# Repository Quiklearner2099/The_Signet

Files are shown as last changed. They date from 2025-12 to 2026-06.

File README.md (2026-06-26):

<div align="center">







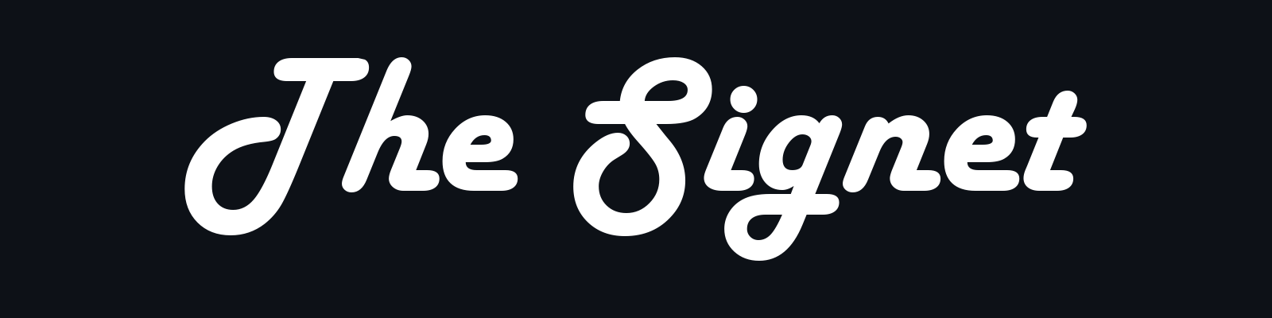
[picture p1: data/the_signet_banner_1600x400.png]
The Signet banner



[]()
[]()
Visitors

<h1>BIG BROTHER IS WATCHING YOU…<br/>Send him a message.</h1>

<strong>A Morse Code Beacon for Protest Messaging / Video Steganography</strong>

<p>
  <strong>The Signet</strong> is a small, WiFi configurable beacon designed to embed a message
  (<strong>encoded in Morse code</strong>)<br>into <strong>recorded video footage</strong>
  using a blinking light source.
</p>

<!-- ADD HERE -->
<a href="https://www.tindie.com/products/signet-systems/the-signet/">
  
</a>

</div>

<div align="center">

---

### **NEW TO THE SIGNET?**

<a href="https://quiklearner2099.github.io/The_Signet/Tutorial/tutorial_demo.html">
  
</a>

**Learn how to use The Signet in minutes with our step-by-step interactive guide!**

---

</div>

## Feature Breakdown

<div align="center">

| 🔩 Hardware | 💾 Firmware |
|:---|:---|
| **XIAO ESP32-C6 SoC** — cheap, small, capable | **Plain text → International Morse code** signaling |
| **Dual emitters** — RGB LED + 950nm IR LED | **Language agnostic** — enc/decodes the same worldwide |
| **500 mAh Li-Po** with dis/charge protection | **Visible / Discreet modes** — selectable RGB / IR output |
| **USB-C charging** — can be used while charging | **WiFi AP+CP** — browser-based UI; no app required |
| **Magnetic mounting** — for fast, easy placement | **No internet connectivity** — operates fully offline |
| **Easy assembly and quick builds** | **Auto WiFi shutdown** after 60 seconds of UI inactivity |
| **Snap-fit 3D-printable enclosure** (2 pieces) | **OTA firmware updates** — upload new firmware via the captive portal |
| **Minimal soldering required** | **True stateless design** — zero bytes persisted to flash |

 **NO telemetry, NO accounts, NO bullshyte**

Click [HERE](https://github.com/Quiklearner2099/The_Signet/blob/main/Documentation/The_Signet_Security_Brief_v1.3.0.pdf) to view the Security Brief  
</div>

<hr/>

<h2>Output Modes</h2>

<ul>
  <li>
    <strong>Visible</strong> — uses an <strong>RGB LED</strong> for human-eye detection
    <em>(obvious in person, obvious on camera)</em>
  </li>
  <li>
    <strong>Discreet</strong> — uses an <strong>IR LED</strong> for low-visibility messaging
    <em>(typically not noticeable to most bystanders, but may still be captured on video depending on the camera)</em>
  </li>
</ul>

<hr/>

<h2>Build Guide</h2>

<p>
  Watch the complete 14-minute build tutorial to assemble your own Signet device:
</p>

<div align="center">
  <a href="https://odysee.com/@the_signet:7/Signet_Build_Guide:8?r=DPS7K88vV2efrcF32mZreA2FPBWHjBPD">
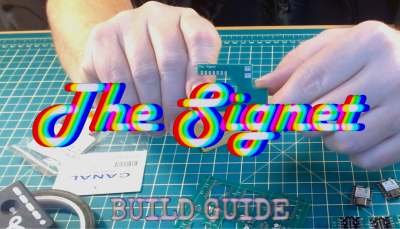
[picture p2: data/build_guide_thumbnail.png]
The Signet Build Tutorial
    
  </a>
  <br>
  <strong>▶️ Click to watch on Odysee</strong>
</div>

<hr/>

<h2>:question:Why this exists</h2>

<h3>:loudspeaker:Durable speech when platforms fail</h3>

<p>
  In many places, digital censorship and content suppression are rising.
  <strong>The Signet</strong> is built for situations where people need to communicate ideas in public—
  especially during peaceful demonstrations—without relying on platforms, audio, or live speech.
</p>

<p>
  Instead of shouting a message (which can provoke instant confrontation or get drowned out),
  <strong>The Signet</strong> lets a message persist inside the footage itself—so it can be discovered later
  in recordings from participants, journalists, or fixed cameras.
  The point is durability: the message travels with the video.
</p>

<blockquote>
  <strong>
    <strong>The Signet</strong> uses standard International Morse Code (ITU), ensuring global readability
    and compatibility with both human and machine decoding. A message embedded in footage can’t be muted, 
    algorithmically downranked, or “lost in the crowd” the same way a post can.
  </strong>
</blockquote>

<h3>:video_camera:Footage continuity &amp; tamper indication</h3>

<p>
  <strong>The Signet</strong> can also be used as a continuity marker for recorded footage.
  By embedding a continuous, time-ordered Morse message into the recording,
  the signal should remain consistent from start to finish.
</p>

<ul>
  <li>
    Unexpected gaps, jumps, or resets may indicate
    cuts, dropped frames, edits, or tampering.
  </li>
  <li>
    This can help viewers and investigators spot continuity breaks
    that might otherwise go unnoticed.
  </li>
</ul>

<hr/>

<h2>:thinking:How this differs from watermarking</h2>

<p>
  While <strong>The Signet</strong> and watermarking both involve embedding information into video,
  they solve very different problems and operate in fundamentally different ways.
</p>

<h3>Watermarking</h3>

<ul>
  <li>Added <strong>after recording</strong> during editing or encoding</li>
  <li>Relies on digital pixel or compression manipulation</li>
  <li>Usually invisible and algorithmic</li>
  <li>Can often be removed or degraded through re-encoding</li>
  <li>Primarily serves ownership and copyright enforcement</li>
</ul>

<h3>The Signet</h3>

<ul>
  <li>Embeds information <strong>at the moment of recording</strong></li>
  <li>Uses optical signaling (visible or IR light)</li>
  <li>Independent of codecs, platforms, and formats</li>
  <li>Becomes part of the physical scene, not a digital layer</li>
  <li>Can reveal edits through continuity breaks</li>
</ul>

<blockquote>
  <strong>Watermarking alters the media.<br/>
  The Signet alters the scene.</strong>
</blockquote>

<hr/>

<h2>:closed_lock_with_key:Privacy &amp; Security by Design</h2>

<ul>
  <li><strong>No app required</strong> — browser-based configuration only</li>
  <li><strong>No internet connectivity</strong> — never connects to cloud services</li>
  <li><strong>Temporary local Wi-Fi AP</strong> for configuration only</li>
  <li><strong>Automatic AP shutdown</strong> after 60 seconds of inactivity</li>
  <li><strong>MAC address locking</strong> — first device to connect gets exclusive access; AP shuts down when that device disconnects</li>
  <li><strong>No persistent logs or telemetry</strong></li>
  <li><strong>True stateless design</strong> — zero bytes written to flash; all settings (including language) reset on power cycle</li>
  <li><strong>OTA updates are local-only</strong> — firmware uploaded directly through the on-device Wi-Fi AP; no cloud, no remote access</li>
  <li><strong>Anti-forensics</strong> — nothing to recover from the device; no message history, no usage patterns</li>
</ul>

<hr/>

## :desktop_computer:Development Setup

### Quick Start with GitHub Codespaces ⭐ RECOMMENDED

The easiest way to contribute is to use GitHub Codespaces - a cloud-based development environment with everything pre-configured:

1. Click the green **"Code"** button on the repository
2. Select the **"Codespaces"** tab
3. Click **"Create codespace on main"**
4. Wait for **"The Signet - ESP32 C6 Arduino"** environment to build (~2-3 minutes)
5. Once ready, you'll have a full VS Code environment with:
   - Arduino CLI pre-installed
   - ESP32 C6 board package configured
   - All required libraries (FastLED, ArduinoJson, etc.)
   - C++ IntelliSense properly configured
   - Ready to compile and verify code

**No local setup required!** All dependencies are handled automatically.

### Local Development (Alternative)

If you prefer to work locally:

1. Install [Arduino IDE 2.x](https://www.arduino.cc/en/software) or [PlatformIO](https://platformio.org/)
2. Install the ESP32 board package (version 3.0.0 or later)
3. Install required libraries via the Library Manager:
   - **FastLED** (v3.5.x)
   - **ArduinoJson** (v6.x)
4. Select board: **ESP32C6 Dev Module**
5. Open `The_Signet.ino` and compile

<h2>Ethical Use</h2>

<p>
  The Signet is intended to support lawful, non-violent freedom of expression,
  documentation, and artistic or journalistic messaging.
  It must not be used to enable harm, harassment, intimidation, illegal activity,
  or to mislead people about what is being recorded or communicated.
</p>

## Support This Project

<a href="https://www.buymeacoffee.com/Quiklearner2099" target="_blank">
  Buy Me A Coffee
</a>

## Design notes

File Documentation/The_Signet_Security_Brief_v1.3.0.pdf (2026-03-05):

# The Signet

# Security Brief — Firmware v1.3.0+

Version 1.3.0 firmware represents the most security-hardened release to date, incorporating lessons from two independent audits and real-world field testing. Every design decision prioritizes the operator's safety, anonymity, and plausible deniability.

Zero Persistence Architecture

The Signet writes zero bytes to permanent storage during normal operation. Messages exist only in volatile RAM and are irrecoverably destroyed the instant the device loses power. There is no message history, no activity log, no usage record, and no settings file written to flash —ever.
Previous firmware versions stored a two-byte language preference in non-volatile storage. Version 1.3.0 eliminates even this, achieving a fully stateless design. The language selection modal appears fresh on every boot, and the chosen language lives only in RAM for the duration of that session. If the device is seized, powered off, or its battery dies, there is nothing to recover. Flash forensics will find only the firmware binary itself and static UI assets (fonts, images). No user-generated data touches persistent memory under any circumstances.

No Telemetry. No Logs. No Exceptions.

The Signet firmware contains zero outbound network code. There is no HTTP client library, no WiFi client mode, no DNS lookup to external servers, no cloud dependency, no analytics SDK, no crash reporter, and no phone-home mechanism of any kind. This has been verified through static analysis of every `#include` directive and every function call in the codebase.
The device operates exclusively as a WiFi Access Point. It creates a local network that allows a single connection; it never joins one. It serves a web UI to the connected client; it never contacts anything beyond that single direct connection. There are no beacon frames sent to probe for known networks, no mDNS broadcasts, and no service discovery announcements. The only RF emission is the AP's SSID beacon, and even that is time-limited (see below).

MAC Address Locking — Single Operator Exclusivity

When the first device connects to The Signet's WiFi access point and issues any API command, the firmware locks to that device's MAC address. From that point forward, no other device can control The Signet — even if it somehow connects to the WiFi network. The lock persists until the device is power -cycled.
This is enforced at the firmware level through `esp_wifi_ap_get_sta_list()`, comparing the requesting client's MAC against the locked MAC on every API call. Combined with the ESP32's `max_conn=1` parameter (which limits the AP to a single simultaneous WiFi client), this creates a two-layer access control: only one device can connect, and only the first device to authenticate gets command authority.

Automatic AP Shutdown on Disconnect

Version 1.3.0 introduces a critical improvement: when the locked operator disconnects from WiFi, the access point shuts down entirely. The firmware polls the station list each loop iteration, and the moment the locked client's MAC disappears, it executes a full shutdown sequence — DNS server stopped, `WiFi.softAPdisconnect(true)` called, WiFi radio turned off. No second device can connect during any window between disconnect and shutdown because the check runs continuously with no grace period.
After shutdown, the locked MAC address is scrubbed from RAM with `memset(lockedMac, 0, sizeof(lockedMac))`. This is a deliberate anti-forensics measure: even a cold-boot attack or live memory dump after the operator walks away will not reveal which device was controlling The Signet. Morse playback continues uninterrupted — the beacon keeps transmitting its message even with WiFi completely disabled.

Additional technical information and source code can be found at: https://github.com/Quiklearner2099/The_Signet

OTA Combination Lock — Physical Verification for Firmware Updates Over-the-air firmware updates are protected by a hardware-verified combination lock system. Before any firmware binary can be uploaded, the operator must:
1. Request a code — The device generates a random 3-digit code (each digit 1–9) using the ESP32's hardware random number generator (`esp_random()`).
2. Read the code from the LED — The RGB LED blinks the code physically: red blinks for digit one, green blinks for digit two, blue blinks for digit three. For example, 3 red blinks, 7 green blinks, 2 blue blinks = code 372.
3. Enter the code in the web UI — The operator types the three digits into color-coded input fields.
4. Upload the firmware — Only after successful code verification does the upload endpoint accept the binary.
The code is generated fresh each time and invalidated after a single successful use. This means an attacker cannot replay a previously observed code, and they cannot upload firmware without physical line-of-sight to the device's LED. The combination lock transforms OTA security from a pure software problem into a physical presence requirement.
Additionally, the firmware validates uploaded binaries against the ESP32 magic byte (0xE9), rejecting anything that isn't a legitimate ESP32 firmware image. The device uses a dual-partition OTA layout, enabling automatic rollback to the previous working firmware if an update fails mid-write.

60-Second WiFi Exposure Window The Signet's WiFi access point automatically shuts down after 60 seconds of inactivity. This minimizes the window during which the device's SSID is visible to passive WiFi scanners. The operator connects, configures their message, and the AP disappears — all within a brief window. The Morse beacon continues transmitting indefinitely after WiFi shutdown, operating in complete radio silence on the WiFi band.
This is a deliberate privacy trade-off: the unique SSID (which includes a MAC-derived suffix for operator identification of their own device) is only broadcast during the brief configuration period, not during the potentially hours-long transmission phase.

Randomized WiFi Channel Selection Each time The Signet boots, it randomly selects one of the three non-overlapping 2.4 GHz channels (1, 6, or 11) using the ESP32's hardware RNG. This provides automatic interference avoidance in congested RF environments and adds a minor layer of unpredictability — an observer cannot assume the device will always appear on the same channel between power cycles.

Defense-in-Depth Input Validation Every API endpoint enforces strict input validation and payload size limits as a defense against malformed or malicious requests:
- Payload size caps: `/api/update` and `/api/play` reject any request body exceeding 512 bytes (HTTP 413). `/api/language` caps at 256 bytes. These limits prevent buffer-based attacks and flash wear from oversized payloads.
- RGB value constraining: All color values are clamped to 0–255 using `constrain()`, preventing out-of-range writes.
- WPM bounds enforcement: Speed values are validated to the 5–20 WPM range before use, with a division-by-zero guard in the timing calculation.
- Language index validation: Language codes are bounds-checked against the valid range before any array access.
- Firmware header validation: OTA uploads are checked for the ESP32 magic byte (0xE9) before the write begins.

No App Required — Captive Portal Web UI The Signet requires no app installation, no account creation, no download, and no third-party dependency. The operator connects to the WiFi AP, and the device's captive portal detection triggers the web UI automatically. Version 1.3.0+ includes explicit handlers for every major platform's captive portal probe mechanism — Android, iOS, Windows 10/11, macOS, and Firefox — ensuring the UI appears reliably across devices without requiring the operator to manually navigate to an IP address.
This matters for security because there is no app binary that could be discovered on a seized phone, no account that could be subpoenaed, and no download history that could be forensically recovered. The entire interaction happens through a standard web browser session that leaves minimal trace.

Multi-Language Support Without Fingerprinting The Signet supports eight languages — English, Spanish, French, Russian, Simplified Chinese, Traditional Chinese, Farsi, and Arabic — with full right -to-left layout support for Arabic and Farsi. In v1.3.0, the language preference is never written to flash, eliminating it as a potential demographic fingerprint. The selection modal appears on every boot, and the choice is stored only in volatile RAM for that session.
dependencies (ArduinoJson, FastLED). Anyone can audit the code, verify the privacy claims, compile their own build, or fork the project entirely.

# The Signet

BIG BROTHER IS WATCHING YOU…. Send him a message.

Hand Made with Pride in Canada

quiklearner2099@proton.me
https://www.tindie.com/products/signet-systems/the-signet/

Thread Safety & Watchdog Protection

The firmware uses FreeRTOS primitives to ensure safe concurrent operation between the web server (running on the main loop) and the Morse playback task (running on a dedicated core):

- Mutex-protected text access: The message string is guarded by a FreeRTOS semaphore. Both read and write operations acquire the mutex with a 100ms timeout, with a safe fallback to "SOS" if the lock cannot be obtained.
- Atomic playback state: The `playing` flag uses `std::atomic<bool>` for lock-free, thread-safe reads and writes across tasks.
- Fatal mutex failure: If either the text mutex or OTA mutex fails to initialize at boot, the firmware halts execution entirely rather than running in an unsafe state.
- Task Watchdog Timer: A 60-second hardware watchdog timer automatically resets the device if the main loop hangs, protecting against denial-ofservice conditions or firmware bugs that could leave the device unresponsive.

Open Source Transparency

The Signet's firmware is fully open source. The complete `.ino` source code, schematics, and bill of materials are available for inspection. There are no binary blobs, no obfuscated modules, and no proprietary libraries beyond the standard ESP32 SDK and well-audited open-source dependencies (ArduinoJson, FastLED). Anyone can audit the code, verify the privacy claims, compile their own build, or fork the project entirely.

The device also ships unlocked by default — the operator can upload their own firmware at any time. The combination lock protects against unauthorized uploads, not against the owner's right to modify their own hardware.

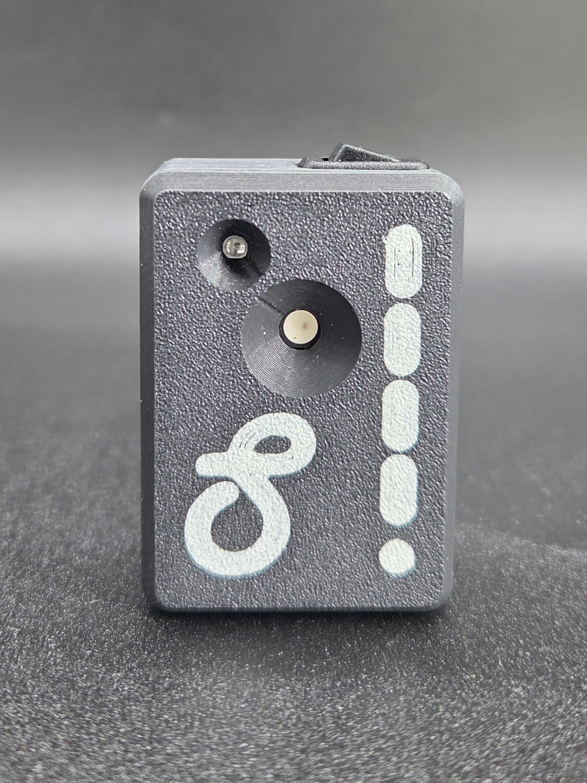
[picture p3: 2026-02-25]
Pictures/Signet 1.JPG

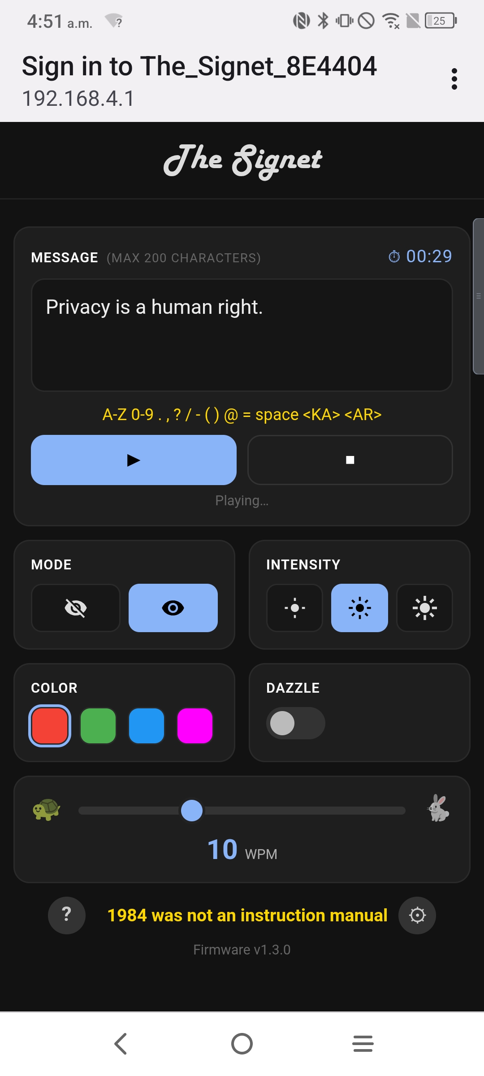
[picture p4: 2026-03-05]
Pictures/Main UI.jpg

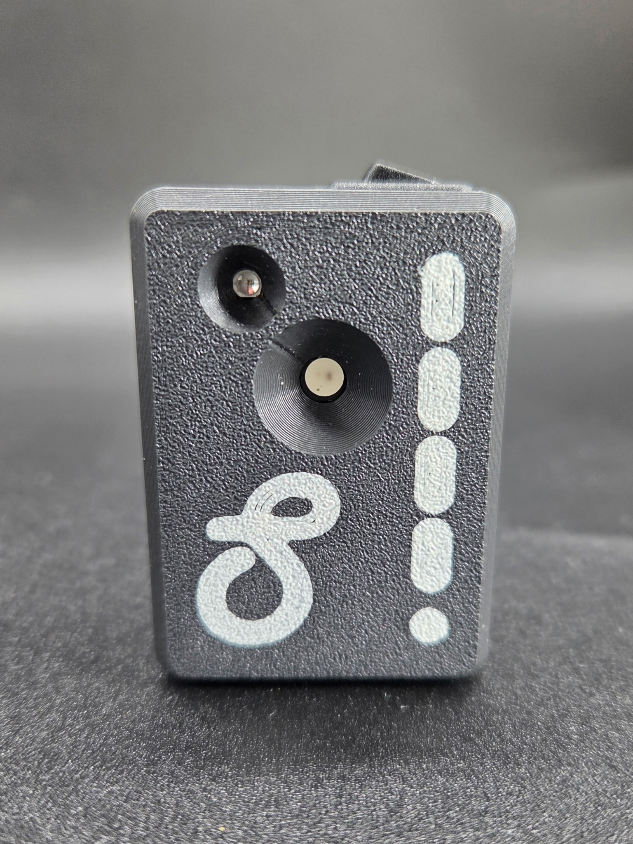
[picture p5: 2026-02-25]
Pictures/Signet 5.JPG

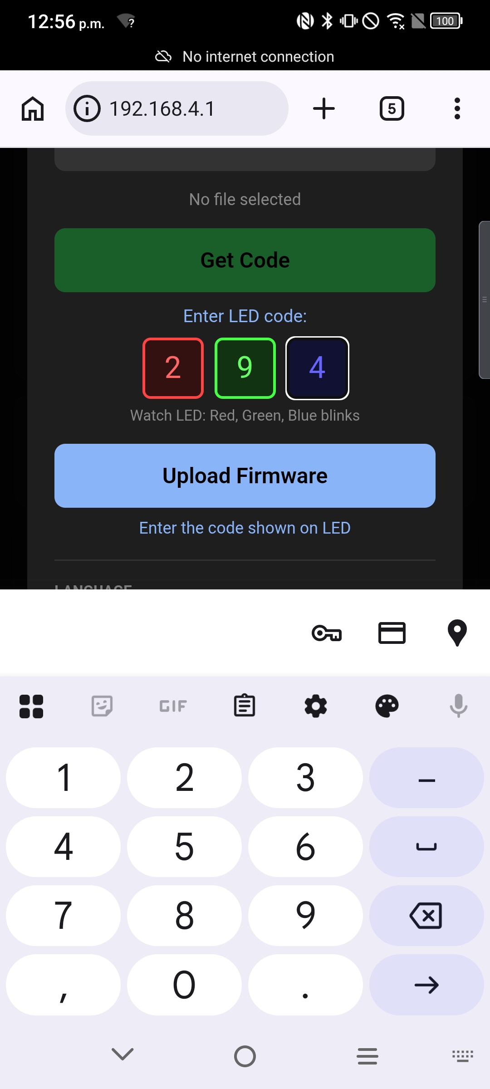
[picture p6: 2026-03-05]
Pictures/Firmware Combo-Lock.jpg

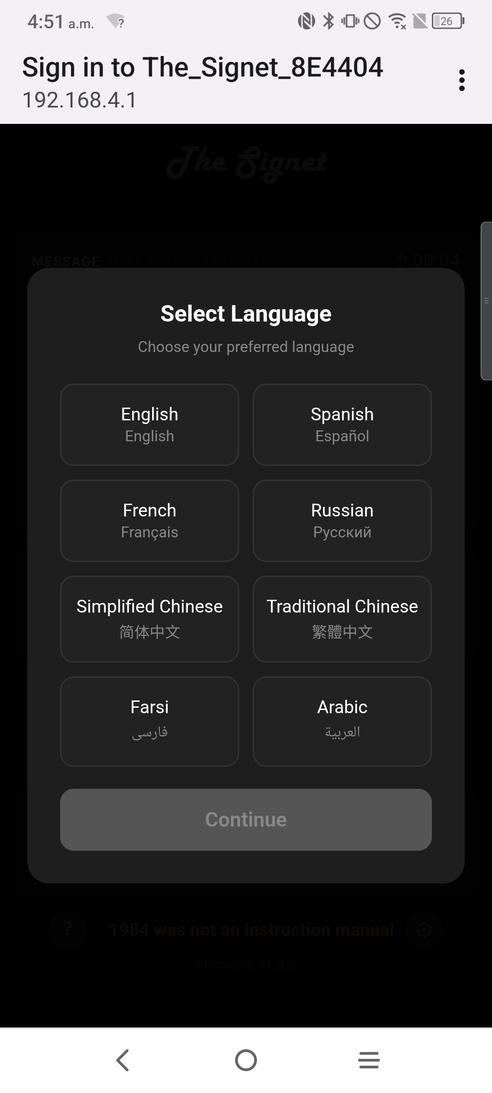
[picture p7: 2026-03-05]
Pictures/Language Selection.jpg

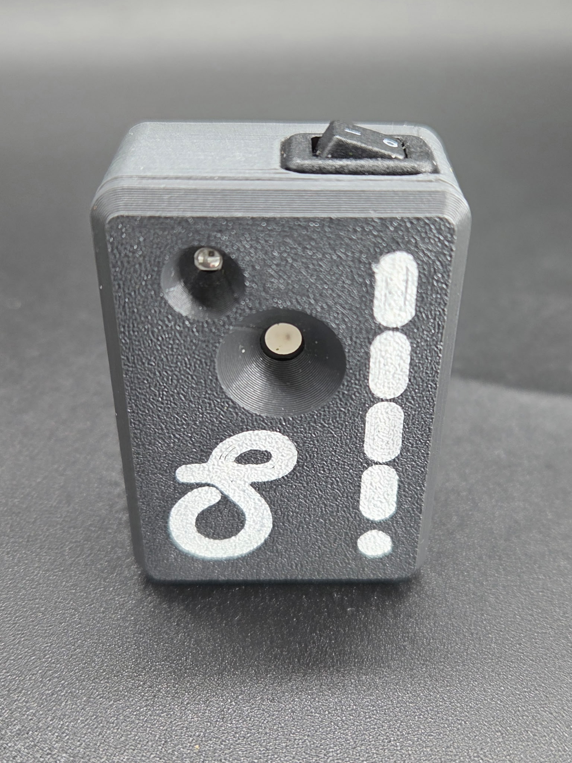
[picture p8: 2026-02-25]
Pictures/Signet 2.JPG

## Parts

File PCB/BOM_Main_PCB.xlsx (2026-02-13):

No. | Quantity | Comment | Designator | Footprint | Value | Manufacturer Part | Manufacturer | Supplier Part | Supplier | LCSC Stock | LCSC Price | JLCPCB Stock | JLCPCB Price
1 | 1 | NTD3528I8 | IR_LED | LED-SMD_L3.5-W2.8-FD-1 |  | NTD3528I8 | 国星光电 | C7464752 | LCSC |  |  | 59830 | 0.0088
2 | 1 | 2N3904 | Q1 | SOT-23-3_L2.9-W1.3-P1.90-LS2.4-BR |  | 2N3904 | GOODWORK(固得沃克) | C50176433 | LCSC |  |  | 6014 | 0.0009
3 | 1 | 47kΩ | R1 | R0805 | 47kΩ | 0805W8F4702T5E | UNI-ROYAL(厚声) | C17713 | LCSC |  |  | 2283443 | 0.0003
4 | 1 | 10Ω | R2 | R1206 | 10Ω | 1206W4F100JT5E | UNI-ROYAL(厚声) | C17903 | LCSC |  |  | 1513848 | 0.0005
5 | 1 | 270Ω | R3 | R0603 | 270Ω | 0603WAF2700T5E | UNI-ROYAL(厚声) | C22966 | LCSC |  |  | 573293 | 0.0002
6 | 1 | 100kΩ | R4 | R0603 | 100kΩ | 0603WAF1003T5E | UNI-ROYAL(厚声) | C25803 | LCSC |  |  | 8972216 | 0.0002
7 | 1 | WS2812B-B/T | RGB_LED | LED-SMD_4P-L5.0-W5.0-TL_WS2812B-B |  | WS2812B-B/T | worldsemi | C2761795 | LCSC |  |  | 167977 | 0.0114

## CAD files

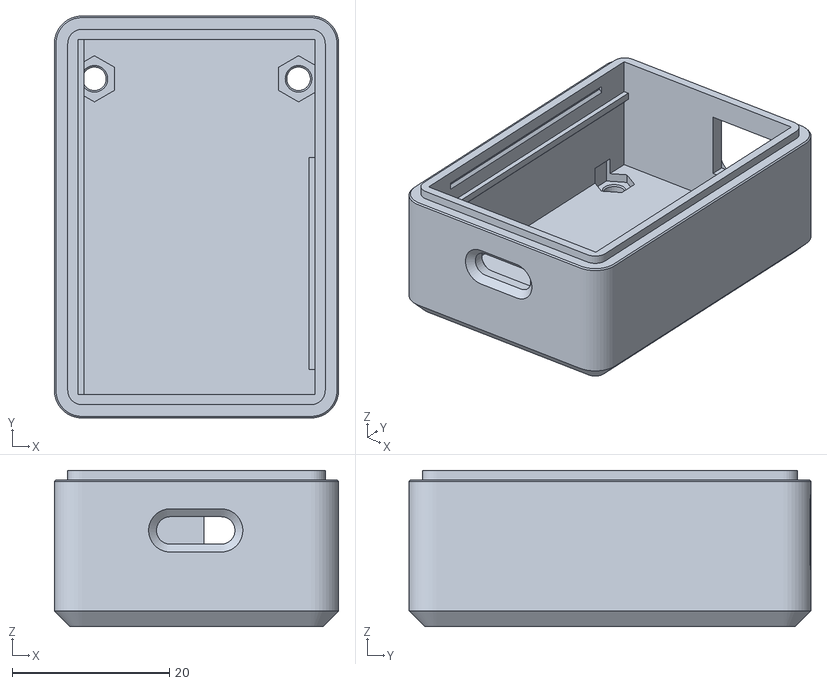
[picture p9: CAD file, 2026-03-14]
Housing/Signet_CASE_Beltclip_Edition.stl
36.2 x 51.2 x 19.9

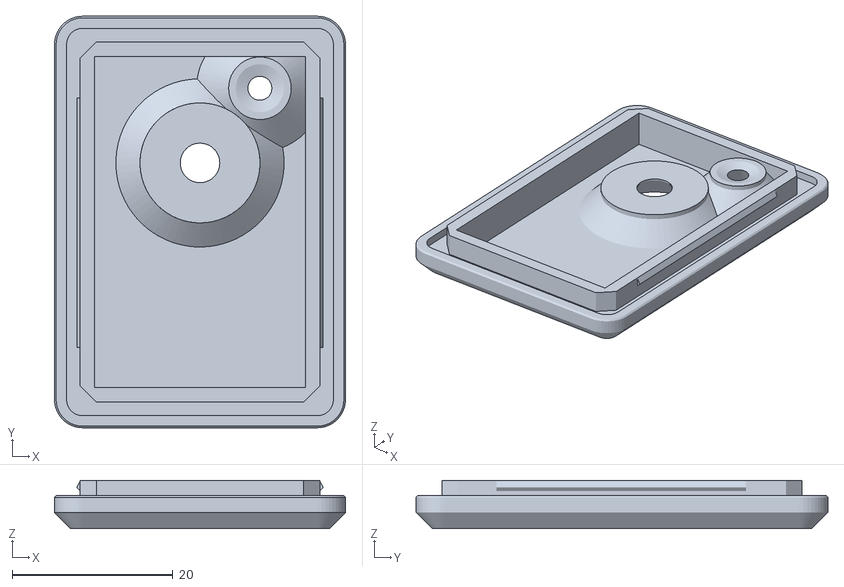
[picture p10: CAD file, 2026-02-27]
Housing/Lid.stl
36.2 x 51.2 x 6.00

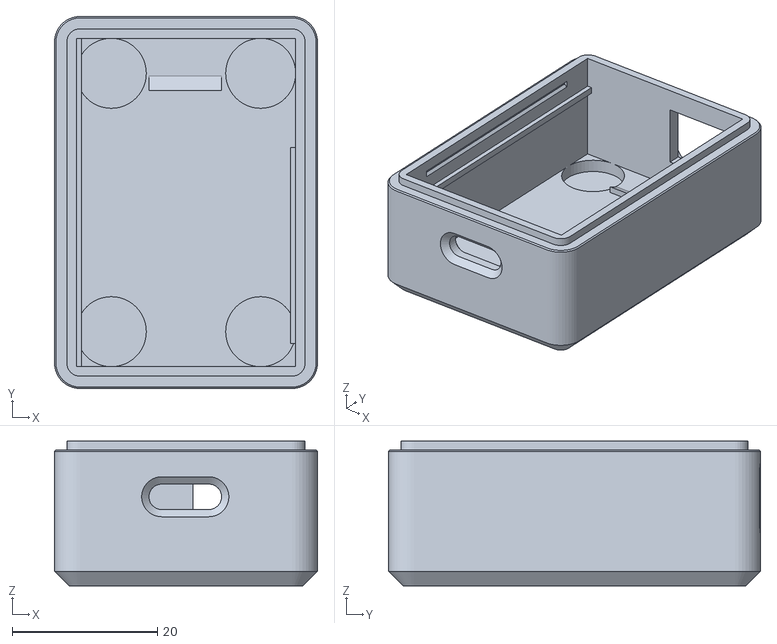
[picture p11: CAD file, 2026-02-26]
Housing/Signet_CASE_9.5x1.6mm_Magnets.stl
36.2 x 51.2 x 19.9

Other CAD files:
Housing/Signet_CASE_10x1.5mm_Magnets.stl

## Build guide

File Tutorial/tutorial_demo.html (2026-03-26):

# The Signet

This interactive tutorial is optimized for desktop viewing.

Please visit on a computer for the best experience.

View on GitHub (https://github.com/Quiklearner2099/The_Signet)

📱

## The Signet

Power on to begin

### Wi-Fi

Wi-Fi

Networks

HomeNetwork_5G📶

Neighbors_WiFi📶

The_Signet_A1B2C3📶

CoffeeShop_Guest📶

9:41

📶 🔋

💬

Messages

📧

Mail

🎵

Music

📷

Photos

❤️

Health

🗺️

Maps

📅

Calendar

⚙️

Settings

📞

🌐

📧

💬

## Select Language

Choose your preferred language

EnglishEnglish SpanishEspañol FrenchFrançais RussianРусский Chinese简体中文 Traditional繁體中文 Farsiفارسی Arabicالعربية

Continue

Big Brother

Click anywhere to send him a message...

← Back to Control

# Morse Code Reference

## Letters

Char | Code | Char | Code | Char | Code
A | ·− | J | ·−−− | S | ···
B | −··· | K | −·− | T | −
C | −·−· | L | ·−·· | U | ··−
D | −·· | M | −− | V | ···−
E | · | N | −· | W | ·−−
F | ··−· | O | −−− | X | −··−
G | −−· | P | ·−−· | Y | −·−−
H | ···· | Q | −−·− | Z | −−··
I | ·· | R | ·−·

## Numbers

Char | Code | Char | Code
0 | −−−−− | 5 | ·····
1 | ·−−−− | 6 | −····
2 | ··−−− | 7 | −−···
3 | ···−− | 8 | −−−··
4 | ····− | 9 | −−−−·

## Prosigns

Tag | Code | Meaning
<KA> | −·−·− | Starting signal
<AR> | ·−·−· | End of message

The Signet

### Message (MAX 200 Characters)00:03

SOS

A-Z 0-9 . , ? / - ( ) @ = space <KA> <AR>

▶ ■

Idle

### Mode

### Intensity

### Color

### Dazzle

RGB flash

🐢

🐇

10 WPM

?1984 was not an instruction manual⚙

Firmware v1.3.1

### Firmware Update

Current: v1.3.1

Choose .bin File

No file selected

Get Code

Enter LED code:

Watch LED: Red, Green, Blue, Yellow blinks

Upload Firmware Close

← Back GitHub Repository (https://github.com/Quiklearner2099/The_Signet) Next →

Step 1 of 15

The Signet

RGB LED (Visible)

IR LED (Discreet)

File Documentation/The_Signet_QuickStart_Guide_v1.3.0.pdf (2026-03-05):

# The Signet

# Quick Start Guide — Firmware v1.3.0

STEP 1: Connect a USB-C cable to charge the device. Power on your Signet using the switch.
STEP 2: On your phone, tablet or computer, open your WiFi Settings and connect to “The_Signet_XXXXXX” where XXXXXX is unique to your device. No password required.
STEP 3: Give the connection a few seconds and the Captive Portal should appear. If not, open any web browser and navigate to http://192.168.4.1
STEP 4: Select your User Interface language from the list of available options that appears. See Figure 1
Note that ITU Morse code implementation remains regardless of selected language.
Step 5: Configure your Signet. See Figure 2

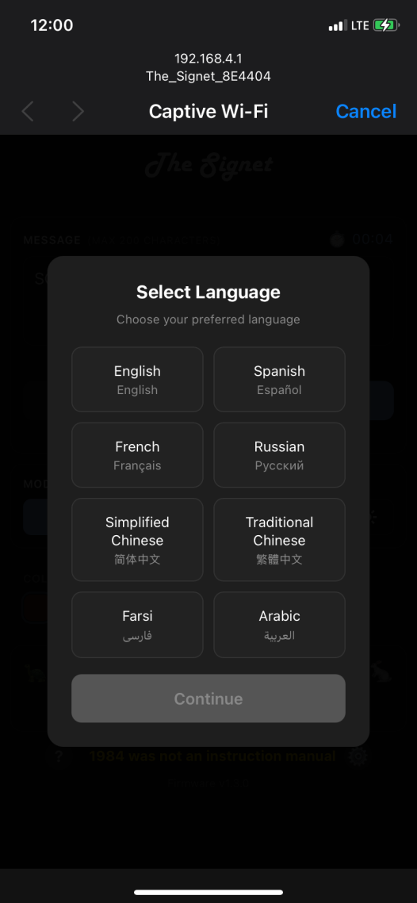
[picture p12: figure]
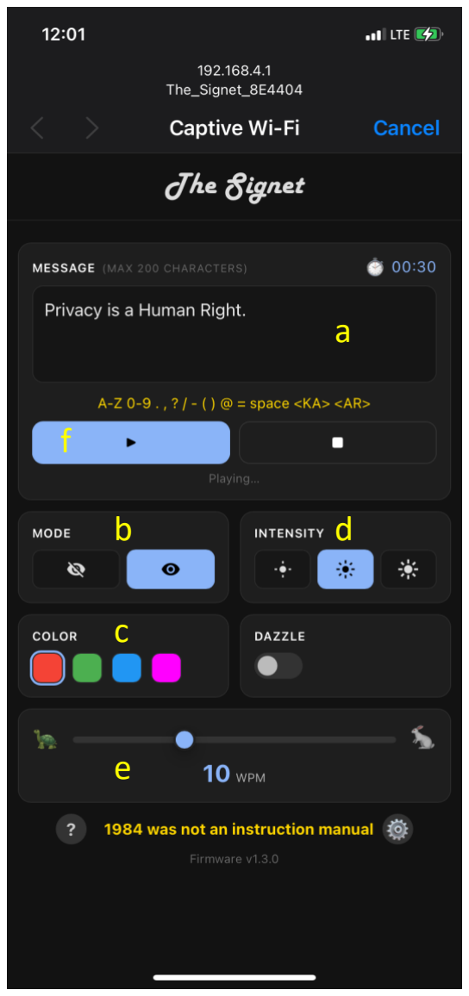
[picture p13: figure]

a. Type in your message (up to 200 Characters)
b. Select Mode: Invisible (IR)* or Visible (RGB)
c. Select Color: R*, G, B, or Custom (Visible Mode only)
d. Select Intensity (Low, Medium* or High)
e. Select your WPM speed (Words Per Minute) 5/10*/15/20
f. Press the Play button to begin message playback.
STEP 6: Close the Captive Portal or web browser and disconnect from the WiFi Access Point. Message playback will continue.
To reconnect, The Signet’s power must be cycled. Turn the switch OFF then ON again to relaunch the WiFi AP. This is normal operation and is meant to conserve battery life, protect your privacy and increase operational security.

*Default values

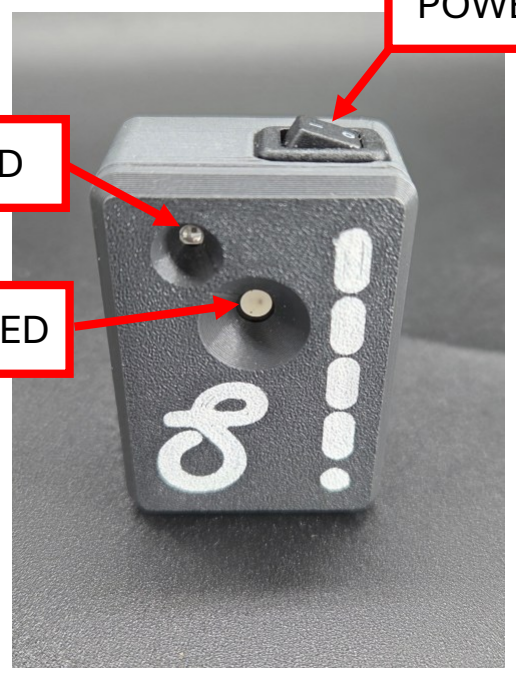
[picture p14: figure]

IR LED

RGB LED

POWER SWITCH

Additional technical information and source code can be found at: https://github.com/Quiklearner2099/The_Signet

iPhone UI examples

Figure 1 | Figure 2

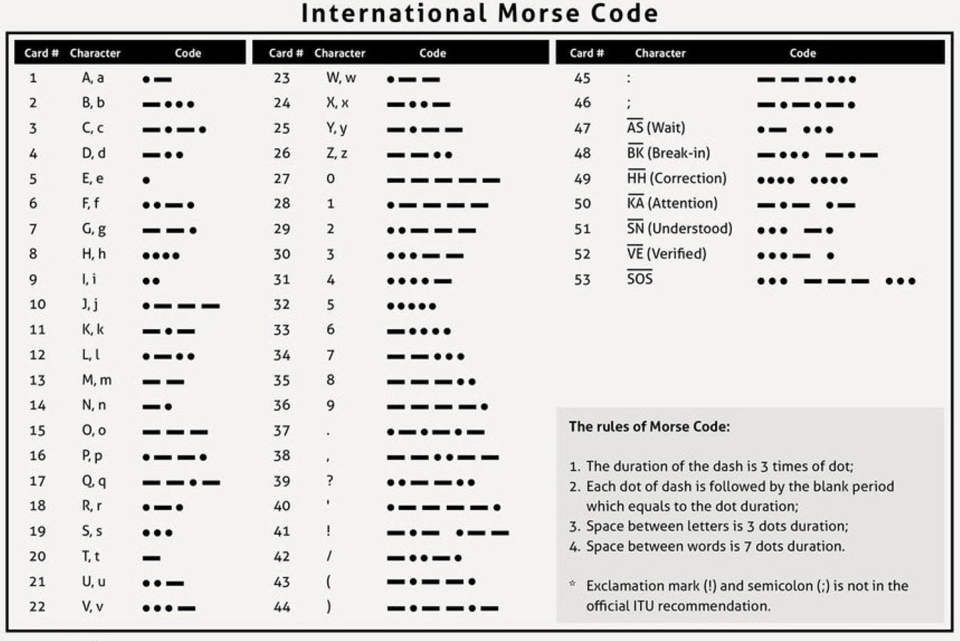
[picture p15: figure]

# The Signet

BIG BROTHER IS WATCHING YOU…. Send him a message.

Hand Made with Pride in Canada

quiklearner2099@proton.me
https://www.tindie.com/products/signet-systems/the-signet/

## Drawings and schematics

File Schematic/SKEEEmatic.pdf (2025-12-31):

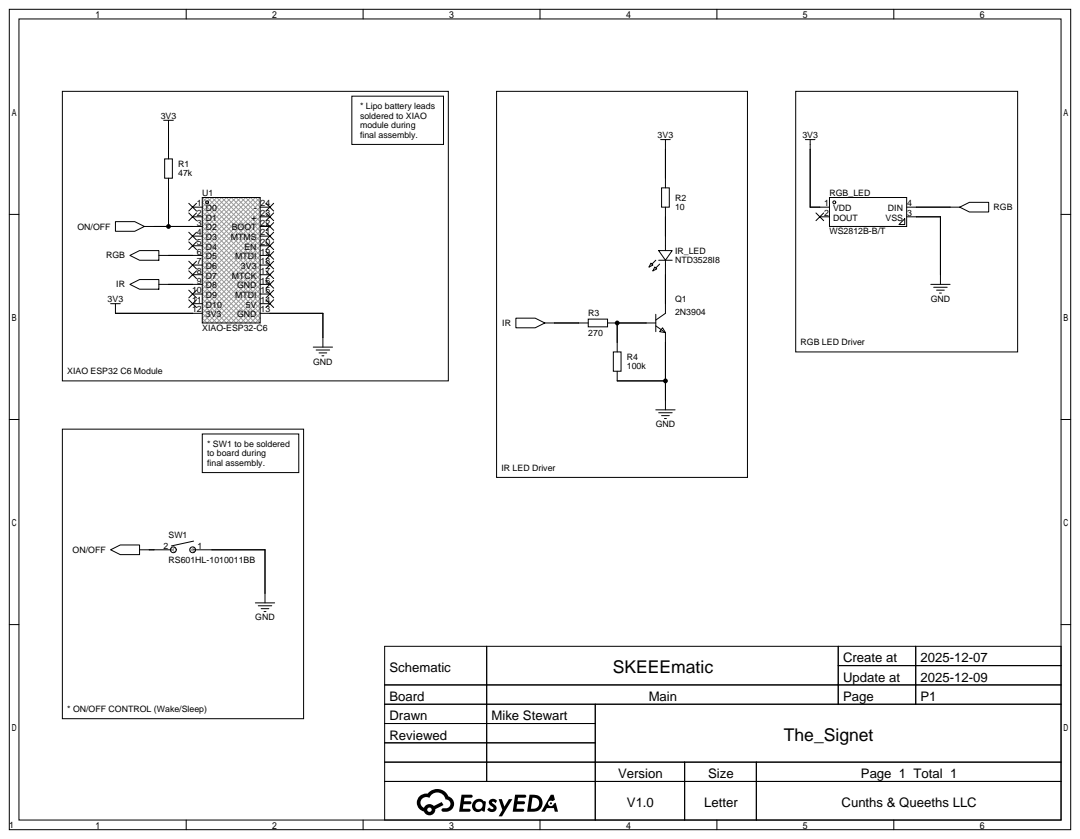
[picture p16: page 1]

Schematic | SKEEEmatic | Create at | 2025-12-07

Update at | 2025-12-09

Board | Main | Page | P1
Drawn | Mike Stewart | The_Signet
Reviewed

* ON/OFF CONTROL (Wake/Sleep)

Version | Size | Page 1 Total 1
V1.0 | Letter | Cunths & Queeths LLC

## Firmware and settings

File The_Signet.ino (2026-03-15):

/*
  ===================================================================================
  The Signet Morse Beacon
  Version: 1.3.1
  Release Date: March 15, 2026
  ===================================================================================

  DESCRIPTION:

  A covert Morse code beacon that can transmit messages via IR (invisible) or RGB 
  (visible) LED. Features a captive portal web interface for configuration and custom
  message input. NO LOGS, NO TELEMETRY, NO BULLSHYTE.

  FEATURES:
  - Wi-Fi AP + Captive Portal Web UI -No APP required
  - SSID: "The_Signet_XXXXXX" (XXXXXX = Last 3 bytes of MAC Address)
  - RGB & IR LED
  - Morse Code Playback with configurable intensity
  - Adjustable Morse speed (5-20 WPM)
  - 60-second idle WiFi AP timeout to conserve power
  - Help(?) screen with Morse code definitions
  - OTA Firmware update support with LED combination lock (v1.3.0+)

  HARDWARE:
  - Seeed Studios XIAO ESP32-C6 Module (other ESP32s can be used)
  - WS2812B RGB LED
  - IR LED
  - 10 Ohm resistor
  - 270 Ohm resistor
  - 47k Ohm resistor
  - 100k Ohm resistor
  - 2N3904 NPN Transistor
  - SPST switch for sleep control
  - (optional) 503035 LiPo battery with built in charge/discharge protection 

  - See schematic for complete circuit

  AUTHOR:
  Created by Mike Stewart as a tool for all those fighting against Authoritarianism
  and to maintain free-speech.

  ===================================================================================
  VERSION HISTORY:
  ===================================================================================
  v1.3.1 (March 15, 2026) - Security hardening: OTA combination lock - 4-digit code
                              displayed via RGB LED (Red/Green/Blue/Yellow blinks) required
                              before firmware upload. Rate limiting with exponential backoff,
                              hard lockout after 5 failed attempts, 3-minute code expiry.
                              OTA serial debug gated behind OTA_DEBUG preprocessor flag.
  v1.3.0 (March 3, 2026) - Security hardening: OTA combination lock - 3-digit code
                              displayed via RGB LED (Red/Green/Blue blinks) required
                              before firmware upload. MAC address locking - first client
                              to connect gets exclusive API access until power cycle.
                              AP now shuts down when locked client disconnects (prevents
                              secondary device WiFi access). Locked MAC cleared from RAM
                              after AP shutdown (anti-forensics). True stateless design:
                              removed NVS language persistence, language modal shows on
                              every boot. Zero bytes persisted to flash.                            
  v1.2.1 (February 26, 2026) - Added UI language options for UI. English (default), French,
                              Spanish, Russian, Traditional Chinese, Simplified Chinese, Arabic and Farsi.
                              *** ITU Morse code is still implemented ***
  v1.2.0 (February 20, 2026) - OTA firmware updates via web UI. Settings gear icon added
                              to footer, opens firmware upload modal with password
                              protection. Dual-partition layout enables automatic rollback
                              on failed updates. Requires one-time USB flash from v1.1.x.
  v1.1.2 (February 19, 2026) - Bugfix: TX time display now updates correctly when message
                              speed (WPM) is modified (Issue #24). Custom message no longer
                              reverts to default when selecting options before Play (Issue #25).
                              Fixed race condition where blue pulse and playback could both
                              control LED after quick power cycle (Issue #26). API now returns
                              proper error responses for invalid requests (Issue #27).
  v1.1.1 (January 27, 2026) - UI improvements: larger help icon and 1984 footer text,
                              firmware version indicator, splash screen text and
                              improved load reliability, Harlow font title, yellow
                              message hints, white card titles, iOS auto-zoom fix,
                              IR PWM frequency increased from 200 Hz to 30 kHz
  v1.1.0 (January 21, 2026) - Default message "S O S" changed to "SOS" for standard
                              Morse timing
  v1.0.3 (January 19, 2026) - Blue pulsing LED indicates WiFi AP ready, 4 rapid blinks
                              confirm Web UI connection, custom color wheel picker,
                              hardware PWM for IR LED (improved power efficiency)
  v1.0.2 (January 3, 2026) - Compact mobile-friendly UI
  v1.0.1 (January 2, 2026) - Added adjustable Morse speed (WPM)
  v1.0.0 (January 1, 2026) - Initial Stable Release

  ===================================================================================
  PIN CONFIGURATION: for Seeed Studios ESP32-C6
  ===================================================================================
  PIN_RGB      D5    - WS2812B RGB LED data
  PIN_IR       D8    - IR LED PWM drive
  PIN_SLEEP_SW D2    - Sleep switch (SPST to GND)

  ===================================================================================
*/

#include <Arduino.h>
#include <WiFi.h>
#include <WebServer.h>
#include <DNSServer.h>
#include <FastLED.h>
#include <ArduinoJson.h>
#include <LittleFS.h>
#include "esp_sleep.h"
#include "esp_mac.h"   // esp_read_mac()
#include "driver/ledc.h"  // Hardware PWM for IR LED
#include <Update.h>       // OTA firmware updates
#include "esp_ota_ops.h"  // OTA boot validation
// Preferences.h removed - true stateless design (no NVS usage)
#include <atomic>         // Thread-safe atomic types
#include "esp_task_wdt.h" // Task watchdog timer
#include "esp_wifi.h"     // MAC address locking

// Increase main loop task stack size from 8KB to 32KB
// Required for WebServer handling multiple captive portal requests (especially Android)
SET_LOOP_TASK_STACK_SIZE(32 * 1024);

// -------------------- Version Information --------------------
#define FIRMWARE_VERSION "1.3.1"
#define FIRMWARE_DATE    "March 15, 2026"

// -------------------- Forward Declarations --------------------
enum Mode     { DISCREET = 0, VISIBLE = 1 };
enum ColorSel { C_RED = 0, C_GREEN = 1, C_BLUE = 2, C_CUSTOM = 3 };
enum Intensity{ I_LOW = 0, I_MED = 1, I_HIGH = 2 };

// Language codes for UI localization
enum Language : uint8_t {
  LANG_EN = 0,     // English (default)
  LANG_ES = 1,     // Spanish (Español)
  LANG_FR = 2,     // French (Français)
  LANG_RU = 3,     // Russian (Русский)
  LANG_ZH_CN = 4,  // Simplified Chinese (简体中文)
  LANG_ZH_TW = 5,  // Traditional Chinese (繁體中文)
  LANG_FA = 6,     // Farsi/Persian (فارسی)
  LANG_AR = 7      // Arabic (العربية)
};

// Language code strings for API
const char* const LANG_CODES[] = {"en", "es", "fr", "ru", "zh-CN", "zh-TW", "fa", "ar"};
const uint8_t LANG_COUNT = 8;

uint8_t  rgbBrightnessFor(Intensity i);
uint8_t  irDutyFor(Intensity i);
CRGB     colorValue(ColorSel c);
String   intensityToStr(Intensity i);
Intensity strToIntensity(const String& s);
String   colorToStr(ColorSel c);
ColorSel strToColor(const String& s);

void setupIrHardwarePwm();
void morseTask(void* pv);

void sendIndex();
void sendHelpPage();
void handleState();
void handleUpdate();
void handlePlay();
void handleStop();
void handleOtaUpload();
void handleOtaComplete();
void handleOtaCode();
void handleLanguageSet();
void handleNotFound();

bool  captivePortal();
void  updateBluePulse();
void  connectionConfirmBlink();
void  goToDeepSleep();

// -------------------- Pins & Hardware --------------------
// Adjust these to match your wiring.
#define PIN_RGB      D5
#define PIN_IR       D8
#define NUM_PIXELS   1

// Sleep switch: SPST between D2 and GND
// CLOSED  -> D2 = LOW  -> run normally
// OPEN    -> D2 = HIGH (INPUT_PULLUP) -> deep sleep
#define PIN_SLEEP_SW D2

// -------------------- Hardware PWM (LEDC) for IR LED --------------------
#define IR_LEDC_CHANNEL  LEDC_CHANNEL_0
#define IR_LEDC_TIMER    LEDC_TIMER_0
#define IR_LEDC_FREQ_HZ  30000  // 30 kHz PWM frequency

// -------------------- WiFi AP -------------------------
const char* AP_SSID_BASE = "The_Signet";
const char* AP_PASS      = "";

IPAddress apIP(192,168,4,1);
IPAddress apGateway(192,168,4,1);
IPAddress apSubnet(255,255,255,0);

String apSsid;  // must persist (global) so c_str() stays valid
String portalRedirectUrl;  // Pre-computed redirect URL to reduce heap pressure in handlers

static String buildApSsidWithMacTail() {
  uint8_t mac[6] = {0};
  // Read factory-programmed MAC from eFuse
  esp_read_mac(mac, ESP_MAC_WIFI_STA);

  char tail[7]; // 6 hex chars + null
  snprintf(tail, sizeof(tail), "%02X%02X%02X", mac[3], mac[4], mac[5]);

  String base(AP_SSID_BASE);
  while (base.endsWith("_")) base.remove(base.length() - 1);

  return base + "_" + tail;
}

// -------------------- WiFi Idle timeout logic --------------------
const unsigned long AP_IDLE_TIMEOUT_MS = 60000; // 60 seconds (privacy: minimize SSID exposure)
unsigned long lastActivityMs = 0;
bool apRunning = false;

inline void noteActivity() { lastActivityMs = millis(); }

// -------------------- UI Connection State & Blue Pulse --------------------
volatile bool uiServed = false;              // True once Web UI has been served
static uint8_t pulseState = 10;              // Current brightness (10-90)
static int8_t pulseDirection = 5;            // Direction and step size
static unsigned long lastPulseMs = 0;
const unsigned long PULSE_INTERVAL_MS = 30;  // Update every 30ms for smooth breathing

// -------------------- Servers -----------------------------
WebServer server(80);
DNSServer dnsServer;

// Language selection: Stateless design - modal shows every boot, no NVS persistence

// -------------------- RGB via FastLED ---------------------
CRGB leds[NUM_PIXELS];

// -------------------- Hardware PWM (LEDC) for IR -----------------
void setupIrHardwarePwm() {
  ledc_timer_config_t timer_conf = {
    .speed_mode = LEDC_LOW_SPEED_MODE,
    .duty_resolution = LEDC_TIMER_8_BIT,
    .timer_num = IR_LEDC_TIMER,
    .freq_hz = IR_LEDC_FREQ_HZ,
    .clk_cfg = LEDC_AUTO_CLK
  };
  ledc_timer_config(&timer_conf);

  ledc_channel_config_t channel_conf = {
    .gpio_num = PIN_IR,
    .speed_mode = LEDC_LOW_SPEED_MODE,
    .channel = IR_LEDC_CHANNEL,
    .intr_type = LEDC_INTR_DISABLE,
    .timer_sel = IR_LEDC_TIMER,
    .duty = 0,
    .hpoint = 0
  };
  ledc_channel_config(&channel_conf);
}

inline void irSetDuty(uint8_t duty) {
  ledc_set_duty(LEDC_LOW_SPEED_MODE, IR_LEDC_CHANNEL, duty);
  ledc_update_duty(LEDC_LOW_SPEED_MODE, IR_LEDC_CHANNEL);
}

// -------------------- App State --------------------------
static SemaphoreHandle_t textMutex = nullptr;

struct AppState {
  volatile Mode mode = DISCREET;
  volatile ColorSel color = C_RED;
  volatile Intensity intensity = I_MED;
  volatile bool dazzle = false;
  volatile uint8_t wpm = 10;  // Words per minute (5-20 range)
  volatile uint8_t customR = 255;  // Custom color RGB components
  volatile uint8_t customG = 0;
  volatile uint8_t customB = 255;  // Default: magenta
  volatile uint8_t language = LANG_EN;  // UI language
  String text = "SOS";
  std::atomic<bool> playing{false};  // Thread-safe playback state
} state;

// -------------------- Security: MAC Address Locking --------------------
// First client to make a POST request gets exclusive access until power cycle
static uint8_t lockedMac[6] = {0};
static bool macLocked = false;

// -------------------- Security: OTA Debug Gating --------------------
// Uncomment to enable OTA serial debug output (SECURITY: code printed in plaintext!)
// #define OTA_DEBUG
#ifdef OTA_DEBUG
  #define OTA_LOG(fmt, ...) Serial.printf(fmt, ##__VA_ARGS__)
  #define OTA_LOGLN(msg)    Serial.println(msg)
#else
  #define OTA_LOG(fmt, ...)
  #define OTA_LOGLN(msg)
#endif

// -------------------- Security: OTA Combination Lock --------------------
// 4-digit code (1-9 each) displayed via RGB LED blinks (R, G, B, Y)
static const uint8_t OTA_CODE_LEN = 4;
static uint8_t otaCode[OTA_CODE_LEN] = {0};
static bool otaCodeValid = false;
static unsigned long otaCodeGeneratedAt = 0;
static const unsigned long OTA_CODE_TTL_MS = 180000UL;  // 3 minutes

// Rate limiting / lockout
static uint8_t otaFailCount = 0;
static unsigned long otaLastFailTime = 0;
static bool otaHardLocked = false;
static unsigned long otaRetryAfterMs = 0;
static const uint8_t OTA_MAX_ATTEMPTS = 5;
static const unsigned long OTA_BACKOFF_BASE_MS = 1000UL;

String getTextCopy() {
  String copy;
  if (textMutex && xSemaphoreTake(textMutex, pdMS_TO_TICKS(100)) == pdTRUE) {
    copy = state.text;
    xSemaphoreGive(textMutex);
  } else {
    copy = "SOS";  // Fallback if mutex fails
  }
  return copy;
}

void setTextSafe(const String& newText) {
  if (textMutex && xSemaphoreTake(textMutex, pdMS_TO_TICKS(100)) == pdTRUE) {
    state.text = newText;
    xSemaphoreGive(textMutex);
  }
}

// -------------------- Brightness / Color -----------------
uint8_t rgbBrightnessFor(Intensity i) {
  switch (i) {
    case I_LOW:  return 40;
    case I_MED:  return 120;
    case I_HIGH: return 200;
    default:     return 120;
  }
}

uint8_t irDutyFor(Intensity i) {
  switch (i) {
    case I_LOW:  return 40;
    case I_MED:  return 120;
    case I_HIGH: return 200;
    default:     return 128;
  }
}

CRGB colorValue(ColorSel c) {
  switch (c) {
    case C_RED:    return CRGB(128,0,0);
    case C_GREEN:  return CRGB(0,128,0);
    case C_BLUE:   return CRGB(0,0,128);
    case C_CUSTOM: return CRGB(state.customR, state.customG, state.customB);
    default:       return CRGB(128,0,0);
  }
}

// -------------------- Morse Timing (WPM-based) -------------------
// Standard "PARIS" timing: dit duration = 1200 / WPM (in ms)
// All other timings are multiples of the dit duration

uint32_t ditDuration()  { uint8_t wpm = state.wpm; return 1200 / (wpm > 0 ? wpm : 1); }  // Guard against div-by-zero
uint32_t dahDuration()  { return 3 * ditDuration(); }
uint32_t gapIntra()     { return ditDuration(); }         // Between dits/dahs in same letter
uint32_t gapLetter()    { return 3 * ditDuration(); }     // Between letters
uint32_t gapWord()      { return 7 * ditDuration(); }     // Between words

// Fixed loop gap timings (not WPM-dependent)
const uint32_t LOOP_GAP = 2000;
const uint32_t VISIBLE_DAZZLE_OFF1 = 750;
const uint32_t VISIBLE_DAZZLE_OFF2 = 750;
const uint32_t VISIBLE_DAZZLE_FLASH = 500;

struct MorseEntry { char ch; const char* code; };
const MorseEntry MORSE[] = {
  {'A',".-"},{'B',"-..."},{'C',"-.-."},{'D',"-.."},{'E',"."},{'F',"..-."},{'G',"--."},{'H',"...."},{'I',".."},{'J',".---"},
  {'K',"-.-"},{'L',".-.."},{'M',"--"},{'N',"-."},{'O',"---"},{'P',".--."},{'Q',"--.-"},{'R',".-."},{'S',"..."},
  {'T',"-"},{'U',"..-"},{'V',"...-"},{'W',".--"},{'X',"-..-"},{'Y',"-.--"},{'Z',"--.."},
  {'0',"-----"},{'1',".----"},{'2',"..---"},{'3',"...--"},{'4',"....-"},{'5',"....."},{'6',"-...."},{'7',"--..."},{'8',"---.."},{'9',"----."},
  {'.',".-.-.-"},{',',"--..--"},{'?',"..--.."},{'/',"-..-."},{'-',"-....-"},{'(',"-.--."},{')',"-.--.-"},{'@',".--.-."},{'=',"-...-"}
};
const size_t MORSE_LEN = sizeof(MORSE) / sizeof(MorseEntry);

const char* lookupMorse(char c) {
  if (c >= 'a' && c <= 'z') c = char(c - 'a' + 'A');
  for (size_t i=0; i<MORSE_LEN; i++) if (MORSE[i].ch == c) return MORSE[i].code;
  return nullptr;
}

// -------------------- Prosigns ---------------------------
struct ProsignEntry { const char* tag; const char* code; };
const ProsignEntry PROSIGNS[] = {
  {"KA", "-.-.-"},   // Starting signal
  {"AR", ".-.-."}    // End of message
};
const size_t PROSIGN_LEN = sizeof(PROSIGNS) / sizeof(ProsignEntry);

const char* lookupProsign(const String& tag) {
  for (size_t i = 0; i < PROSIGN_LEN; i++) {
    if (tag.equalsIgnoreCase(PROSIGNS[i].tag)) return PROSIGNS[i].code;
  }
  return nullptr;
}

// -------------------- LED Control -------------------------
inline void irOff() { irSetDuty(0); }
inline void irOn()  { irSetDuty(irDutyFor(state.intensity)); }

void rgbOff() {
  FastLED.setBrightness(0);
  leds[0] = CRGB::Black;
  FastLED.show();
}

void rgbOnCurrentColor() {
  FastLED.setBrightness(rgbBrightnessFor(state.intensity));
  leds[0] = colorValue(state.color);
  FastLED.show();
}

void activeLedOn()  { if (state.mode == DISCREET) irOn();  else rgbOnCurrentColor(); }
void activeLedOff() { if (state.mode == DISCREET) irOff(); else rgbOff(); }
void allOff() { irOff(); rgbOff(); }

// -------------------- Security: MAC Locking ----------------
// Get connected client's MAC address (only 1 client allowed via max_conn=1)
bool getClientMac(uint8_t* macOut) {
  wifi_sta_list_t stationList;

  if (esp_wifi_ap_get_sta_list(&stationList) != ESP_OK) return false;
  if (stationList.num == 0) return false;

  // With max_conn=1, there's only ever one client
  memcpy(macOut, stationList.sta[0].mac, 6);
  return true;
}

// Check if request is from locked MAC, or lock to first client
bool checkMacLock() {
  uint8_t clientMac[6];

  // If can't get MAC, allow (fallback for reliability)
  if (!getClientMac(clientMac)) {
    return true;
  }

  // First client - lock to their MAC
  if (!macLocked) {
    memcpy(lockedMac, clientMac, 6);
    macLocked = true;
    Serial.printf("[Security] Locked to MAC: %02X:%02X:%02X:%02X:%02X:%02X\n",
                  lockedMac[0], lockedMac[1], lockedMac[2],
                  lockedMac[3], lockedMac[4], lockedMac[5]);
    return true;
  }

  // Check if same MAC
  return memcmp(clientMac, lockedMac, 6) == 0;
}

// -------------------- Security: OTA Combination Lock -------
// Generate random 4-digit code (1-9 each)
// Note: Must be called with otaMutex held (called from handleOtaCode which acquires it)
void generateOtaCode() {
  for (int i = 0; i < OTA_CODE_LEN; i++) {
    otaCode[i] = (esp_random() % 9) + 1;  // 1-9
  }
  otaCodeValid = true;
  otaCodeGeneratedAt = millis();
  OTA_LOG("[OTA] Generated code: %d%d%d%d\n", otaCode[0], otaCode[1], otaCode[2], otaCode[3]);
}

// Display OTA code via RGB LED blinks: Red=digit1, Green=digit2, Blue=digit3, Yellow=digit4
void displayOtaCodeOnLed(const uint8_t* code) {
  // Stop any current playback
  bool wasPlaying = state.playing;
  state.playing = false;
  delay(200);
  allOff();

  // Blink pattern: Red, Green, Blue, Yellow for digits 1-4
  CRGB colors[OTA_CODE_LEN] = {CRGB(255,0,0), CRGB(0,255,0), CRGB(0,0,255), CRGB(255,255,0)};

  for (int digit = 0; digit < OTA_CODE_LEN; digit++) {
    delay(500);  // Pause between digits
    for (int blink = 0; blink < code[digit]; blink++) {
      leds[0] = colors[digit];
      FastLED.setBrightness(200);
      FastLED.show();
      delay(300);
      leds[0] = CRGB::Black;
      FastLED.show();
      delay(200);
    }
  }

  delay(300);
  allOff();

  // Restore playback state if needed
  if (wasPlaying) state.playing = true;
}

// Verify OTA code - invalidates after successful use
// Note: Must be called with otaMutex held (called from handleOtaUpload which acquires it)
bool verifyOtaCode(uint8_t d1, uint8_t d2, uint8_t d3, uint8_t d4) {
  if (!otaCodeValid) return false;
  // Check TTL expiry
  if ((millis() - otaCodeGeneratedAt) > OTA_CODE_TTL_MS) {
    otaCodeValid = false;
    memset(otaCode, 0, OTA_CODE_LEN);
    OTA_LOGLN("[OTA] Code expired");
    return false;
  }
  bool match = (d1 == otaCode[0] && d2 == otaCode[1] && d3 == otaCode[2] && d4 == otaCode[3]);
  if (match) {
    otaCodeValid = false;  // Invalidate after successful use
    OTA_LOGLN("[OTA] Code verified successfully");
  } else {
    OTA_LOG("[OTA] Code verification failed: got %d%d%d%d, expected %d%d%d%d\n",
                  d1, d2, d3, d4, otaCode[0], otaCode[1], otaCode[2], otaCode[3]);
  }
  return match;
}

// -------------------- Morse Task --------------------------
TaskHandle_t morseTaskHandle = nullptr;
inline void morseDelay(uint32_t ms) { vTaskDelay(pdMS_TO_TICKS(ms)); }
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
void loop(){
  // If switch is OPEN at any time, go to deep sleep (with debounce)
  if (digitalRead(PIN_SLEEP_SW) == HIGH) {
    delay(50);  // Debounce delay
    if (digitalRead(PIN_SLEEP_SW) == HIGH) {  // Confirm still HIGH
      goToDeepSleep();
    }
  }

  if (apRunning) {
    dnsServer.processNextRequest();
    server.handleClient();

    // Security: If MAC is locked and locked client disconnected, shut down AP
    if (macLocked) {
      wifi_sta_list_t stationList;
      if (esp_wifi_ap_get_sta_list(&stationList) == ESP_OK) {
        bool lockedClientPresent = false;
        for (int i = 0; i < stationList.num; i++) {
          if (memcmp(stationList.sta[i].mac, lockedMac, 6) == 0) {
            lockedClientPresent = true;
            break;
          }
        }
        if (!lockedClientPresent) {
          Serial.println("[Security] Locked client disconnected - shutting down AP");
          dnsServer.stop();
          WiFi.softAPdisconnect(true);
          WiFi.mode(WIFI_OFF);
          apRunning = false;
          allOff();
          // Clear locked MAC from memory (defense-in-depth)
          memset(lockedMac, 0, sizeof(lockedMac));
          macLocked = false;
        }
      }
    }

    // Pulse blue LED while waiting for Web UI connection
    if (!uiServed && !state.playing) {
      updateBluePulse();
    }

    // idle timeout -> shut down Wi-Fi
    unsigned long now = millis();
    if ((now - lastActivityMs) > AP_IDLE_TIMEOUT_MS) {
      dnsServer.stop();
      WiFi.softAPdisconnect(true);
      WiFi.mode(WIFI_OFF);
      apRunning = false;
      allOff();
    }
  }

  // Feed the watchdog timer (prevents reset during normal operation)
  esp_task_wdt_reset();
}

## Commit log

2025-12-31 File Created
    Arduino IDE Code
2025-12-31 Initial Upload
    [Front_Signet.stl, Rear_Signet.stl]
2025-12-31 PCB Gerber Files
2026-01-01 Update comment for IR LED pin configuration
2026-01-04 Fix spelling error: 'resisitor' to 'resistor' in hardware list
    [The_Signet.ino]
2026-01-20 v1.0.3: Blue pulse indicator, custom color wheel, hardware PWM
    - Blue pulsing LED indicates WiFi AP ready (replaces color cycling)
    - 4 rapid blue blinks confirm Web UI connection
    - Custom color wheel picker for RGB mode
    - Hardware PWM (LEDC) for IR LED improves power efficiency
    - Web UI performance fixes: throttled canvas redraws, reduced polling
    - Simplified color wheel (removed brightness slider)
    [The_Signet.ino]
2026-02-19 Codespace devcontainer
    devcontainer configuration for ESP32 C6 Arduino
2026-02-19 Add setup script for Arduino CLI and ESP32
    This script installs Arduino CLI, sets up its configuration, and installs the ESP32 board package.
2026-02-19 Modify setup script for ESP32 development
    Updated ESP32 board package version and added required libraries.
2026-02-19 Add CMake tools and Arduino settings to devcontainer
2026-02-19 Update devcontainer.json for Arduino configuration
2026-02-19 Enhance setup script for Arduino environment
    Added verification for library installation and created .vscode directory.
2026-02-19 Add C/C++ configuration for ESP32-C6
2026-02-25 Pictures added
    Pictures of Device and User Interface.
2026-02-26 Updated Case Design
    [Signet_CASE_10x1.5mm_Magnets.stl, Signet_CASE_9.5x1.6mm_Magnets.stl]
2026-02-27 UI Languages
    Added language selection.
    [partitions.csv]
2026-02-27 file cleanup
    Remove old 3D Print files
    [Front_Signet.stl, Rear_Signet.stl]
2026-02-27 Remove old STL files
    [Front_Signet.stl, Rear_Signet.stl]
2026-02-27 Updated Lid Design
    [Lid.stl]
2026-03-03 v1.3.0 Update
    v1.3.0 Security Update
    [partitions.csv]
2026-03-05 docs: Add firmware signing evaluation to session memory
    Documented analysis of firmware signing for The Signet:
    - Evaluated existing OTA security model (LED code, MAC lock, AP isolation)
    - Concluded signing is unnecessary given current defenses
    - Noted conflicts with open-source and stateless design philosophy
    - Branch feature-signedfw closed as exploratory
2026-03-05 chore: Update .gitignore and untrack session memory
    - Fixed MEMORY filename case/spelling in .gitignore
    - Untracked MEMORY_v1.3.0_SESSION.md (local dev file)
2026-03-05 feat: Update interactive tutorial to v1.3.0
    Tutorial changes (13 → 15 stages):
    - Add Stage 4: Language Selection modal (8 languages, RTL support)
    - Add Stage 14: Firmware Update (OTA with LED code verification)
    - Update all UI elements to match v1.3.0 firmware:
    - Play/Stop buttons: icon-only (no text labels)
    - Mode buttons: eye icons (eye-slash=IR, open eye=RGB)
    - Intensity buttons: LED ray icons (4/8/8-thick rays)
    - Speed card: tortoise/hare icons, centered WPM display
    - Footer: settings gear button added
    - Message header: TX time display added
    - Update stage content for icon-based UI descriptions
    - Update version display from v1.1.1 to v1.3.0
    Firmware fix:
    - AP_IDLE_TIMEOUT_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
    [The_Signet.ino]
2026-03-05 fix: Restore v1.3.0 security features
    The tutorial update commit (58642c8) accidentally reverted most v1.3.0
    security hardening. This commit restores:
    - std::atomic<bool> for thread-safe playback state
    - Captive portal detection (Android, iOS, Windows, Firefox)
    - WiFi channel randomization (1, 6, 11)
    - Single connection limit (max_conn=1)
    - Watchdog timer (60s timeout)
    - OTA size verification
    - FATAL halt on mutex creation failure
    - IP address validation
    - Division-by-zero guard
    [The_Signet.ino]
2026-03-14 Added new Case option
    [Signet_CASE_Beltclip_Edition.stl]
2026-03-15 feat: Merge v1.3.0 mitigations into Dev, add v1.3.1 OTA security hardening
    Merge main into Dev to pick up all v1.3.0 security features (max_conn=1,
    robust IP validation, fatal mutex halt, atomic playback state, WDT, captive
    portal OS handlers, WiFi channel randomization, 60s idle timeout, RGB
    constrain, div-by-zero guard). Resolve merge conflicts keeping v1.3.1
    OTA_DEBUG-gated log macros over plain Serial.printf calls.
    Fix documentation bug: OTA code TTL was documented as "5-minute" in version
    history comment but actual value is 3 minutes (180000ms). Corrected to
    "3-minute" in both The_Signet.ino and CLAUDE.md.
    Add comprehensive security audit report (SECURITY_AUDIT_v1.3.1_Dev.md).
    Co-Aut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
    [The_Signet.ino]

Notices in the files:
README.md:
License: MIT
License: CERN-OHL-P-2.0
